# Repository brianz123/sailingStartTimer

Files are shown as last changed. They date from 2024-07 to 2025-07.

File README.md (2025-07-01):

# Sailing Start Timer

This project is a microcontroller-based horn system designed to automate race starts for sailboat regattas. It replaces manual countdowns and whistle systems with a reliable, consistent, and rugged solution tailored to race officials on the water.

## Summary

The Sailing Start Timer outputs a sequence of horn blasts that follow standard sailing race countdown rules. A single button press initiates the sequence, allowing race officials to focus on managing boats instead of watching the clock. The system is built with an Arduino and a waterproof speaker, and was designed to be both portable and weather-resistant.

## Features

- Automated horn sequence for 5-minute, 3-minute, or custom countdowns
- One-button operation for simple race start triggering
- Loud, waterproof horn for outdoor use
- Rugged and portable design suitable for mark boats or committee boats
- Custom enclosure and PCB designed for durability

## Hardware

- Arduino microcontroller
- Waterproof speaker module
- Push-button input
- Custom 3D-printed or machined enclosure
- Power system for extended outdoor operation (e.g. 12V or battery pack)

## Software

- Written in Arduino C++
- Timer-based logic to produce horn blasts at key intervals
- Debounced user input handling
- Configurable countdown intervals via code or DIP switches (if implemented)

## How It Works

1. User presses a button to trigger the countdown.
2. The microcontroller runs a timed sequence of horn blasts:
   - Long horn at 5:00
   - Warning signals at 4:00, 1:00, and 0:00 (based on racing rules)
3. Horn blasts are output through a waterproof horn module at full volume.
4. System resets automatically or after user input.

## Use Case

This device is intended for use by sailing race officials on the water. It simplifies race starts, ensures consistent timing, and reduces errors from manual systems.

## Author

**Brian Zagalsky**

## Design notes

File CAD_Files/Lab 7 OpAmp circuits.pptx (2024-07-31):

## Op Amp: Nearly ideal differential voltage amplifier

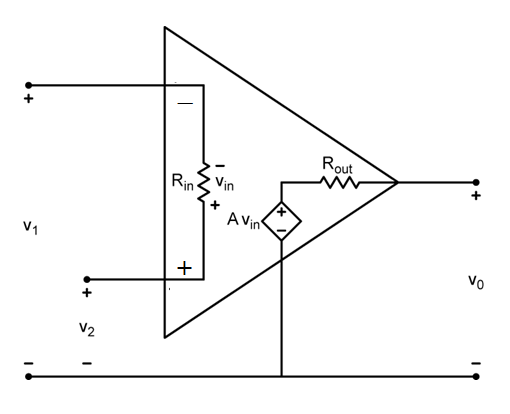
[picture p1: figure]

Ideal op-amp:

A→ ∞

Rin→ ∞

Rout→0

## Before you build a circuit, you need to draw circuit diagram, and a wiring diagram

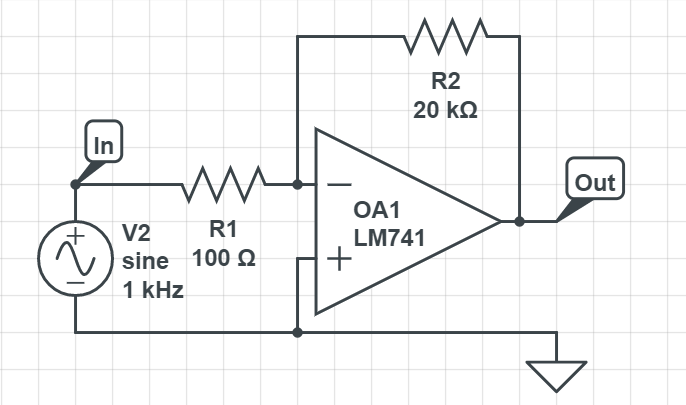
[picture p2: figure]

This is a circuit diagram:

Wiring diagram includes the connections specific pins on the chip,
and to the power supplies

## This is a wiring diagram for non-inverting amplifier

V ⁻

V⁺

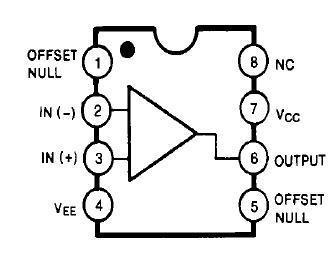
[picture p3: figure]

Input signal

Output
to oscilloscope

R1

R2

Ground

Ground

## Inverting amplifier

vs

+

R1

v1

v2

+

+
Vout

R2

This amplifier works as designed provided Vout is in the range
between V⁻ and V⁺

Clipping of output signal occurs when the amplitude of Vout is too high

## Summing amplifier

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
vout

Vout= - Rf (VS1/R1+VS2/R2)

## Different pulse shapes can be observed when we add harmonics to sinusoidal signals

clear
t=0:1000;
omega=2*pi/200;
V1=cos(omega*t)-(1/3)*cos(3*omega*t)
+(1/5)*cos(5*omega*t);
figure(1);plot(t,V1)

With large number of harmonics
the output approaches the
square wave

## Different pulse shapes can be observed when we add harmonics to sinusoidal signals

clear
t=0:1000;
omega=2*pi/200;
V1=cos(omega*t)+(1/3)*cos(3*omega*t)
+(1/5)*cos(5*omega*t);
figure(1);plot(t,V1)

With large number of harmonics
the output approaches the
triangular wave

## All real amplifiers have a finite bandwidths

Bandwidth is the range of frequencies
for which the device works properly

Our OpAmp circuits work well for low frequencies, down to DC

Bandwidth in this case is defined as the frequency
for which the output power gain is down to 50%
of the design value

Important trade off:
Gain * Bandwidth is approximately a constant

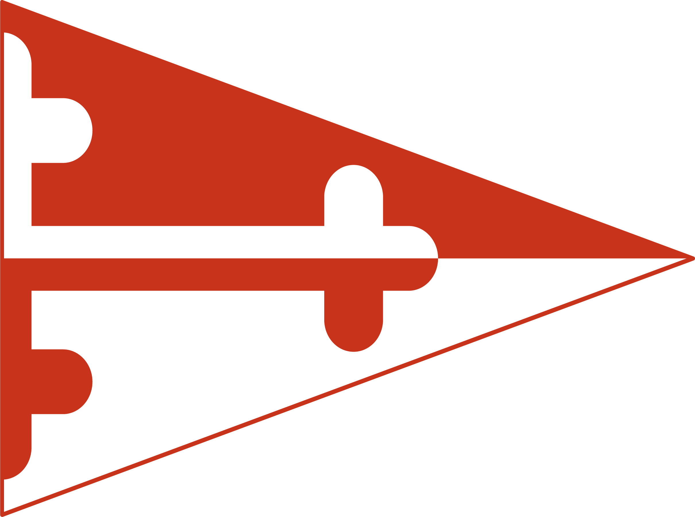
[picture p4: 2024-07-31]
CAD_Files/Burgee.png

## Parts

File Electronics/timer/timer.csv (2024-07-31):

Source: | C:\Users\Brian\Documents\ESP\timer\timer.kicad_sch
Date: | 1/15/2023 2:08:23 PM
Tool: | Eeschema (6.0.7)
Generator: | C:\Program Files\KiCad\6.0\bin\scripting\plugins/bom_csv_grouped_by_value_with_fp.py
Component Count: | 14
Ref | Qnty | Value | Cmp name | Footprint | Description | Vendor
BT1, | 1 | Battery | Battery | Connector_PinSocket_1.00mm:PinSocket_1x02_P1.00mm_Vertical | Multiple-cell battery
LS1, | 1 | Speaker | Speaker | Connector_PinHeader_2.54mm:PinHeader_1x02_P2.54mm_Vertical | Speaker
Q1, | 1 | IRFZ48 | IRFZ48 | Connector_PinHeader_1.00mm:PinHeader_1x03_P1.00mm_Vertical
R1, R2, R3, R4, R5, | 5 | 10k | R | Resistor_THT:R_Axial_DIN0204_L3.6mm_D1.6mm_P7.62mm_Horizontal | Resistor
R6, | 1 | 2.2k | R | Resistor_THT:R_Axial_DIN0204_L3.6mm_D1.6mm_P7.62mm_Horizontal | Resistor
SW1, | 1 | Reset | SW_Push | Button_Switch_THT:SW_PUSH_6mm_H4.3mm | Push button switch, generic, two pins
SW2, | 1 | 2 Min | SW_Push | Button_Switch_THT:SW_PUSH_6mm_H4.3mm | Push button switch, generic, two pins
SW3, | 1 | 3 Min | SW_Push | Button_Switch_THT:SW_PUSH_6mm_H4.3mm | Push button switch, generic, two pins
SW4, | 1 | 5 Min | SW_Push | Button_Switch_THT:SW_PUSH_6mm_H4.3mm | Push button switch, generic, two pins
v1, | 1 | Node_MCU | Node_MCU | ESP:Node MCU

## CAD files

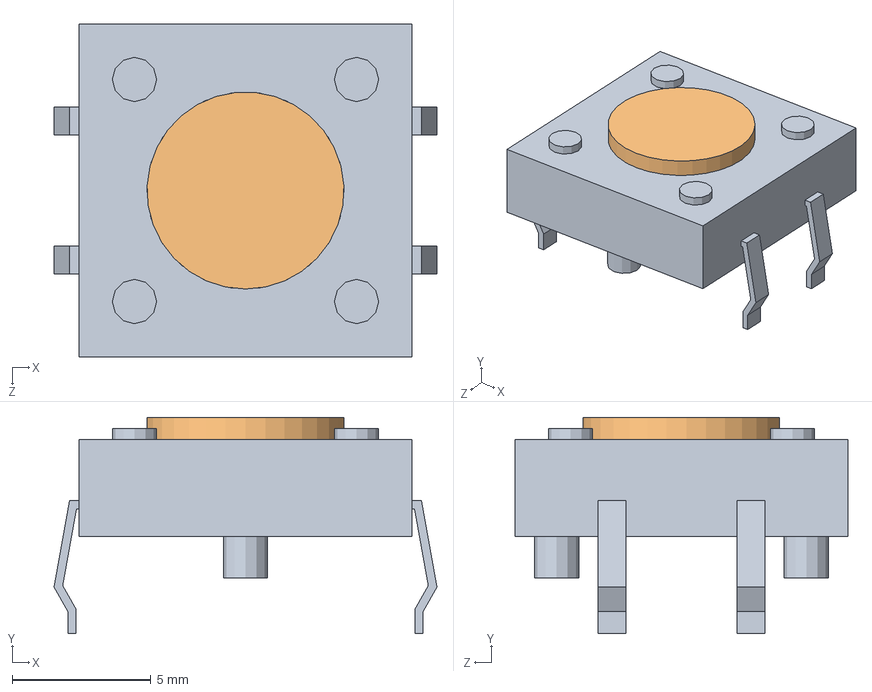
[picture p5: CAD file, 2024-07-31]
CAD_Files/B3F_4000_Solidworks/B3F_4000.SLDASM
13.8 x 7.80 x 12.0 mm
B3F_4000_BASE
B3F_4000_BUTTON

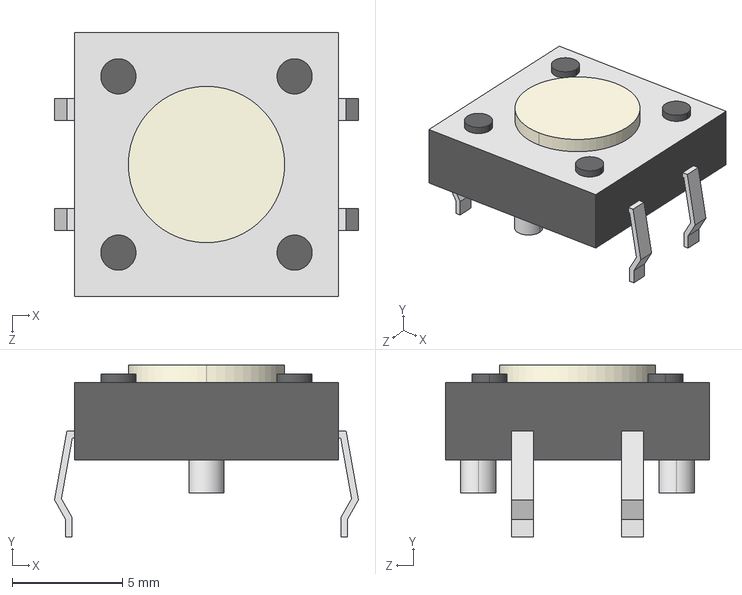
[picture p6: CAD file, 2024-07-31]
CAD_Files/B3F_4000_Solidworks/SW_PUSH_12mm.STEP
13.8 x 7.80 x 12.0 mm
B3F_4000_BASE
B3F_4000_BUTTON

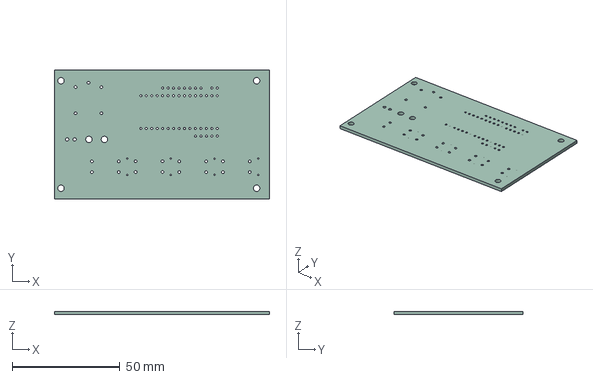
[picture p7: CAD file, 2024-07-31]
CAD_Files/timer.step
100.0 x 60.0 x 1.60 mm

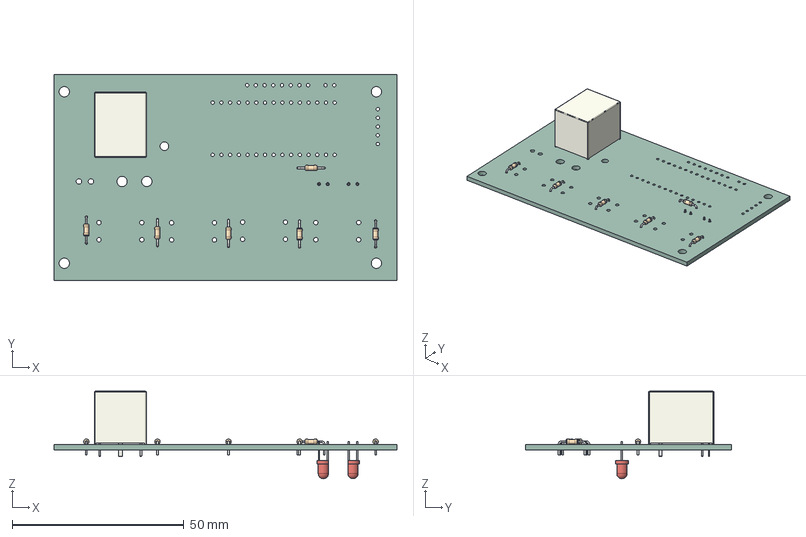
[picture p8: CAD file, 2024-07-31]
Electronics/Timer V4/Timer V4.step
100.0 x 60.0 x 25.5 mm
Timer V4 PCB

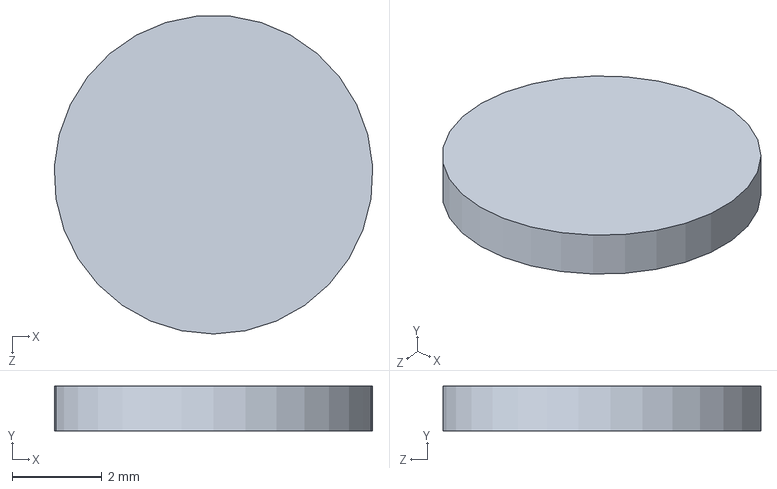
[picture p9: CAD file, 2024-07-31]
CAD_Files/B3F_4000_Solidworks/B3F_4000_BUTTON.SLDPRT
7.09 x 1.00 x 7.08 mm

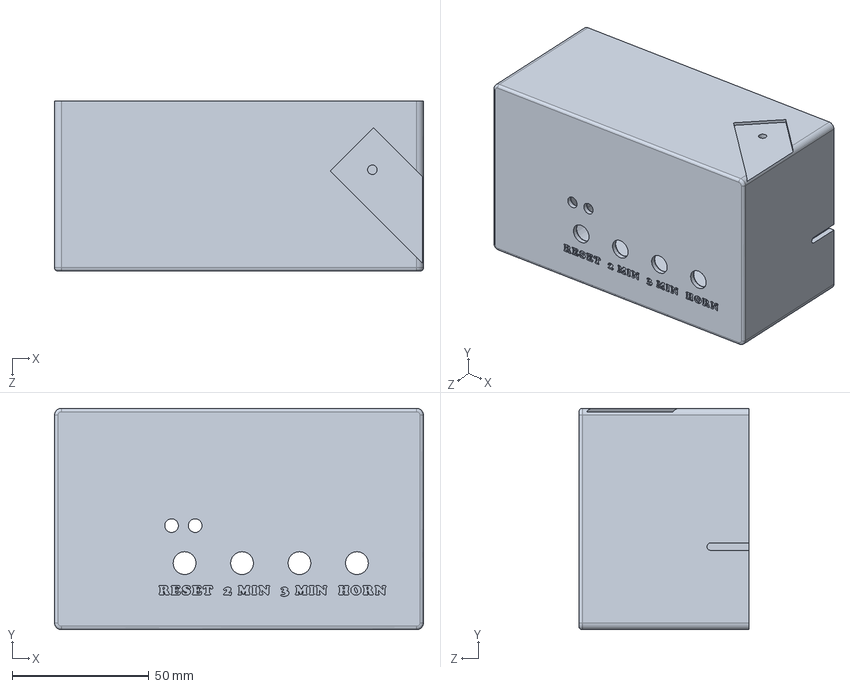
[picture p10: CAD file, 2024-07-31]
CAD_Files/timerBox.SLDPRT
135.0 x 81.0 x 62.2 mm

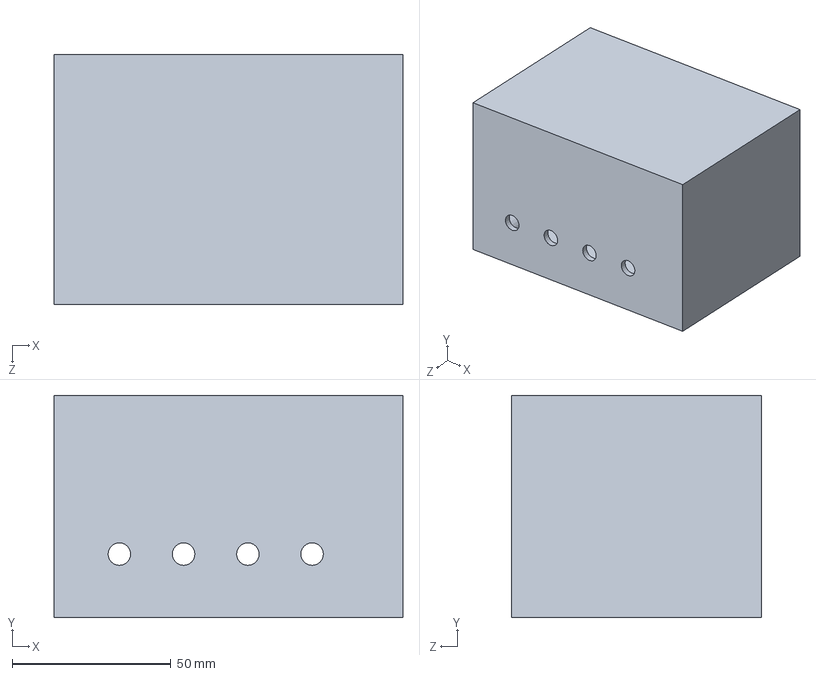
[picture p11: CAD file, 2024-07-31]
CAD_Files/Part1.SLDPRT
110.0 x 70.0 x 78.7 mm

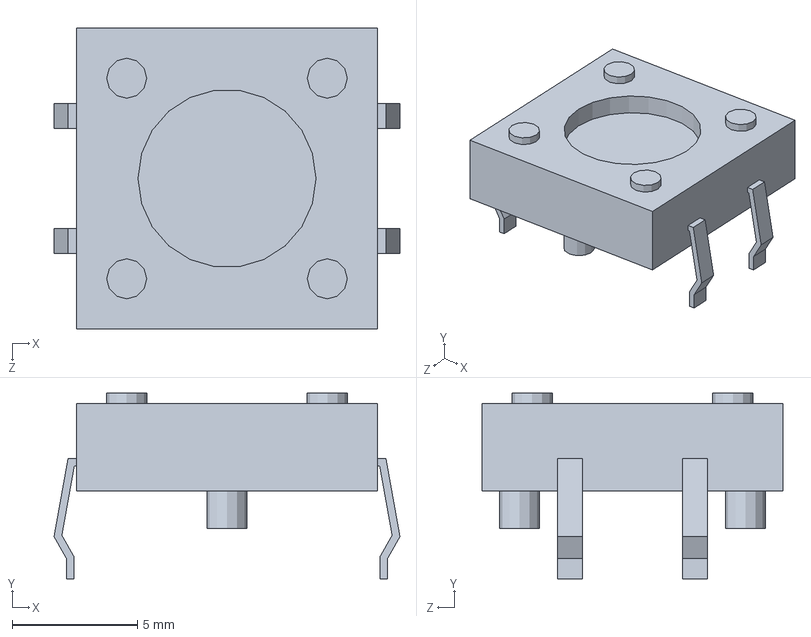
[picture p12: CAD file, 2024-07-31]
CAD_Files/B3F_4000_Solidworks/B3F_4000_BASE.SLDPRT
13.8 x 7.40 x 12.0 mm

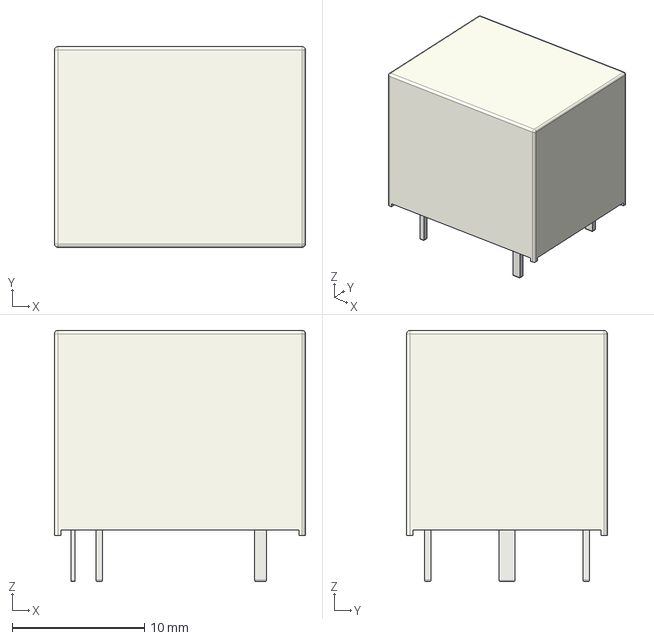
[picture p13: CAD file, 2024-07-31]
CAD_Files/Relay_SPDT_Finder_36.11.step
19.0 x 15.2 x 19.0 mm

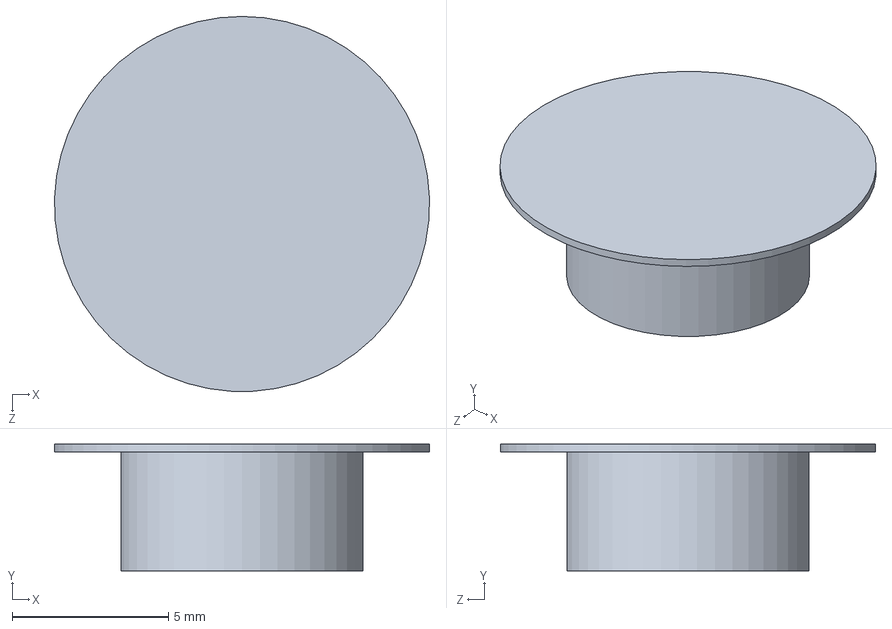
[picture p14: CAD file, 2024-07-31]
CAD_Files/buttunCap.SLDPRT
12.0 x 4.06 x 12.0 mm

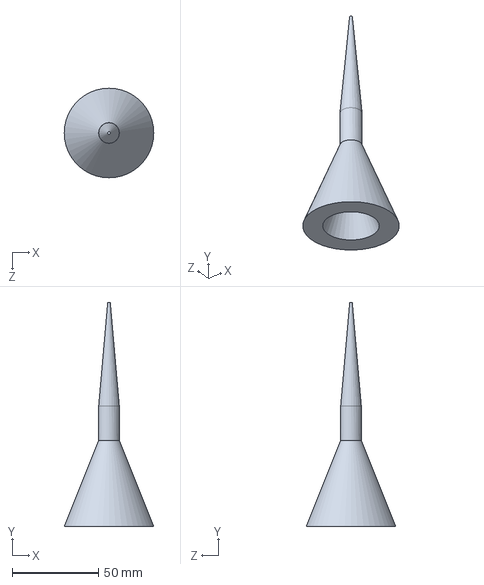
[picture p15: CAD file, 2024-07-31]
CAD_Files/funnel.SLDPRT
52.0 x 130.0 x 52.0 mm

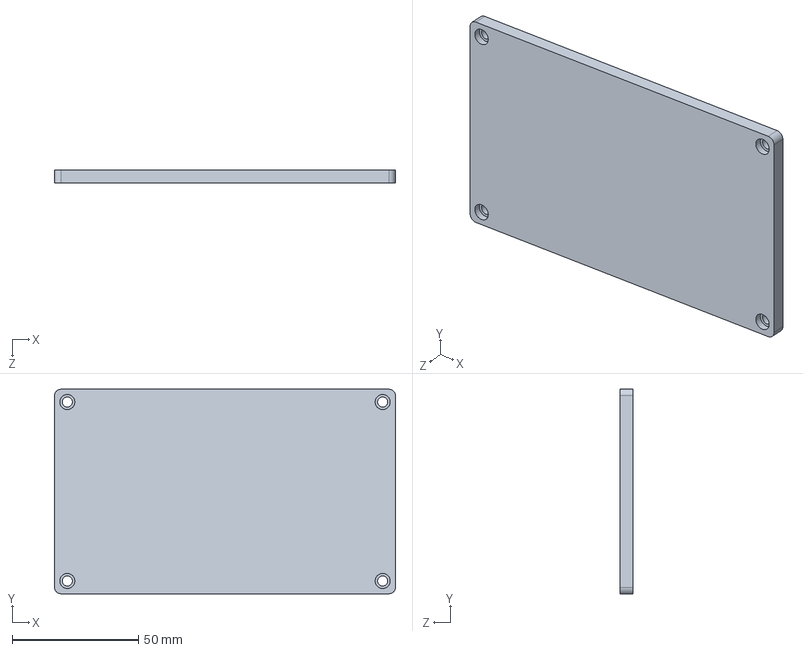
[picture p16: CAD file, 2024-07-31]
CAD_Files/door.SLDPRT
135.0 x 81.0 x 5.08 mm

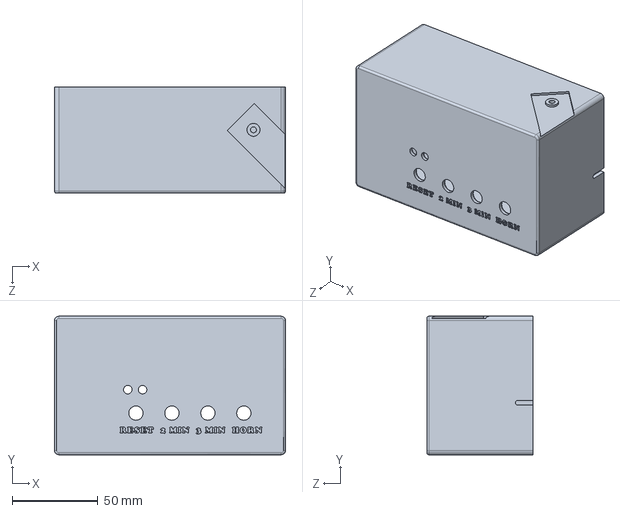
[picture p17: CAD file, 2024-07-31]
CAD_Files/timerBoxV2.SLDPRT
135.0 x 81.0 x 62.2 mm

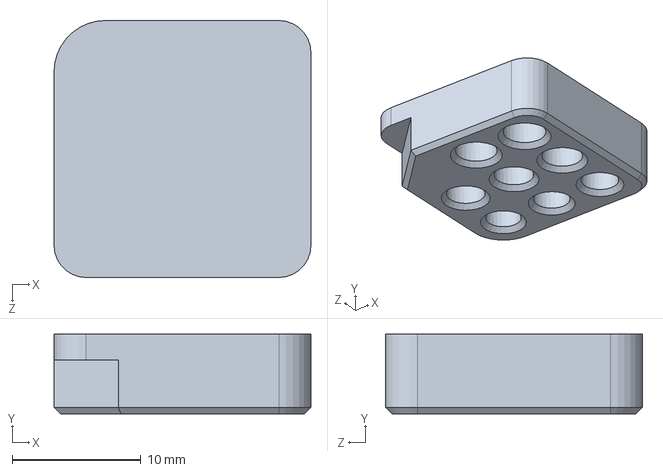
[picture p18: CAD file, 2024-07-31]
CAD_Files/nutTester.SLDPRT
20.0 x 6.20 x 20.0 mm

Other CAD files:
CAD_Files/door V4.STL
CAD_Files/R_Axial_DIN0207_L6.3mm_D2.5mm_P7.62mm_Horizontal.step
CAD_Files/dorr.SLDPRT
CAD_Files/funnelSMALL.STL
CAD_Files/B3F_4000_Solidworks/B3F_4000.SLDDRW
CAD_Files/buttunCap.STL
CAD_Files/door.STL
CAD_Files/funnel.STL
CAD_Files/nutTester.STL
CAD_Files/timer.SLDASM
CAD_Files/timer.STL
CAD_Files/timerBox V4.STL
CAD_Files/timerBox.STL
CAD_Files/timerBoxV2.STL

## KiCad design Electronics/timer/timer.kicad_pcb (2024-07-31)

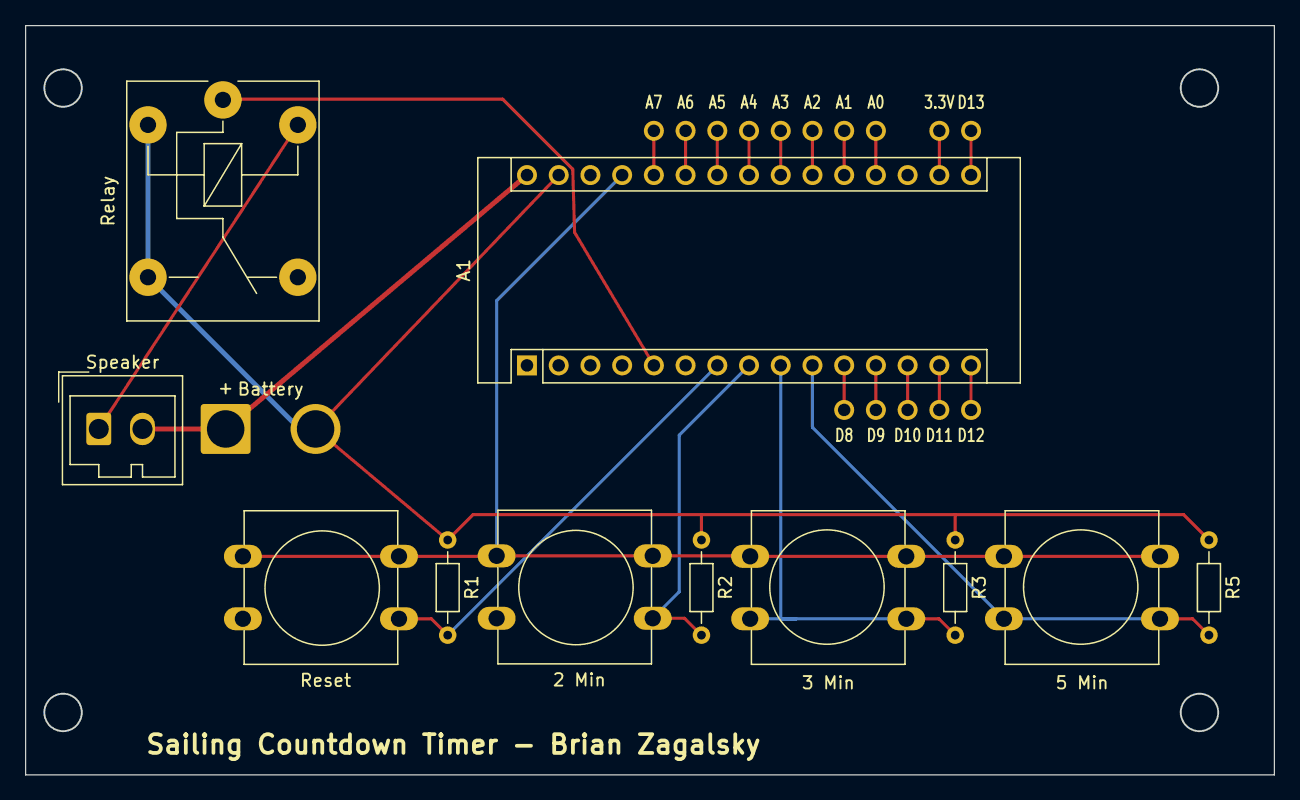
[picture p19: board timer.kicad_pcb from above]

Board: 2 copper layers, 100.0 x 60.0 mm, 27 parts (0 on the bottom side), 9 nets.

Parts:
3.3V: MountingHole_1.2mm
A0, A1, A2, A3, A4, A5, A6, A7: MountingHole_1.2mm
A1#2: Arduino_Nano_v3.x; Arduino_Nano
Battery: Battery; SolderWire-2.5sqmm_1x02_P7.2mm_D2.4mm_OD3.6mm
D8, D9, D10, D11, D12, D13: MountingHole_1.2mm
R1, R2, R3, R5: 10k; R_Axial_DIN0204_L3.6mm_D1.6mm_P7.62mm_Horizontal
Relay: FINDER-36.11; Relay_SPDT_Finder_36.11
SW1: Reset; SW_PUSH-12mm
SW2: 2 Min; SW_PUSH-12mm
SW3: 3 Min; SW_PUSH-12mm
SW4: 5 Min; SW_PUSH-12mm
Speaker: Speaker; Wago_734-132_1x02_P3.50mm_Vertical

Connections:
unnamed: A1#2.5 (D2), Relay.11
unnamed: Relay.A2, Speaker.1
unnamed: A1#2.30 (VIN), Battery.1 (+), Speaker.2
unnamed: A1#2.7 (D4), R1.2, SW1.2
unnamed: A1#2.8 (D5), R2.2, SW2.2
unnamed: A1#2.9 (D6), R3.2, SW3.1
unnamed: A1#2.10 (D7), R5.2, SW4.1
unnamed: A1#2.27 (+5V), SW1.1, SW2.1, SW3.2, SW4.2
unnamed: A1#2.29 (GND), Battery.2 (-), R1.1, R2.1, R3.1, R5.1, Relay.14, Relay.A1

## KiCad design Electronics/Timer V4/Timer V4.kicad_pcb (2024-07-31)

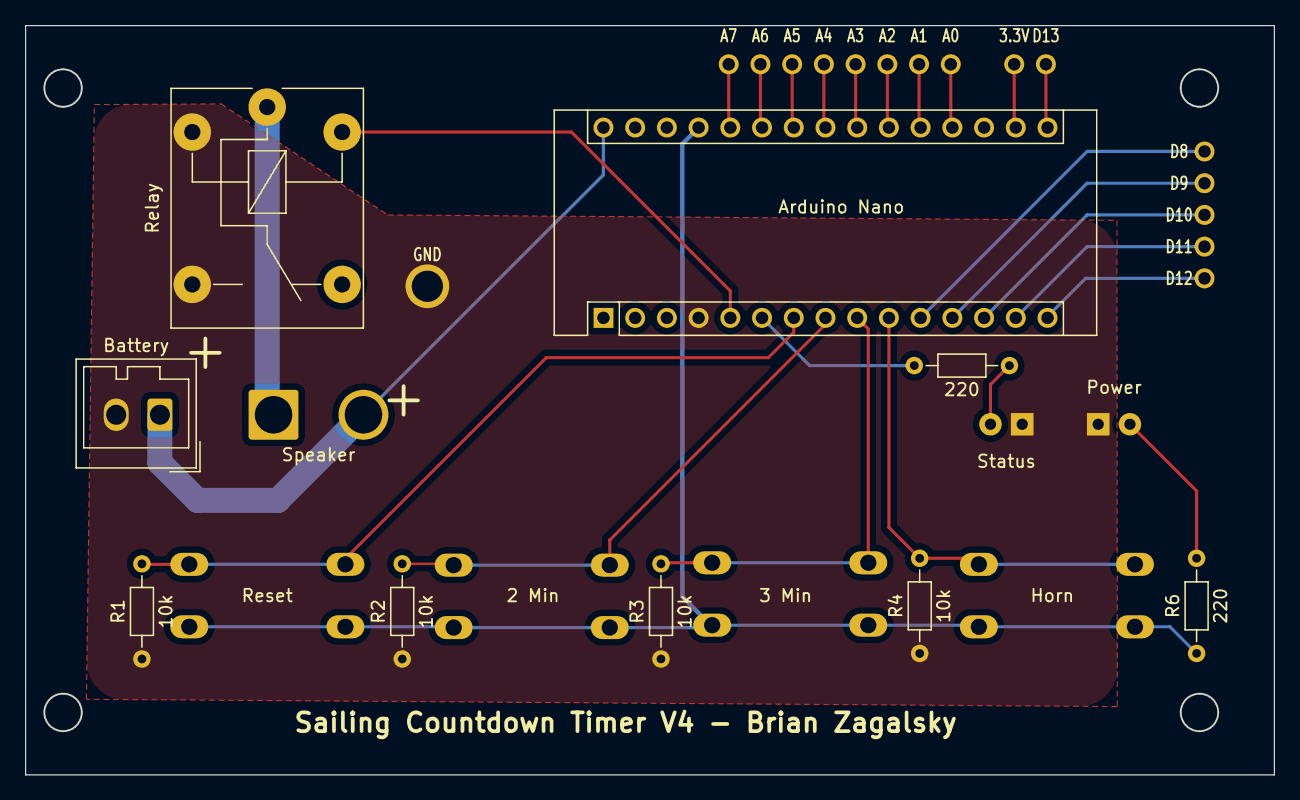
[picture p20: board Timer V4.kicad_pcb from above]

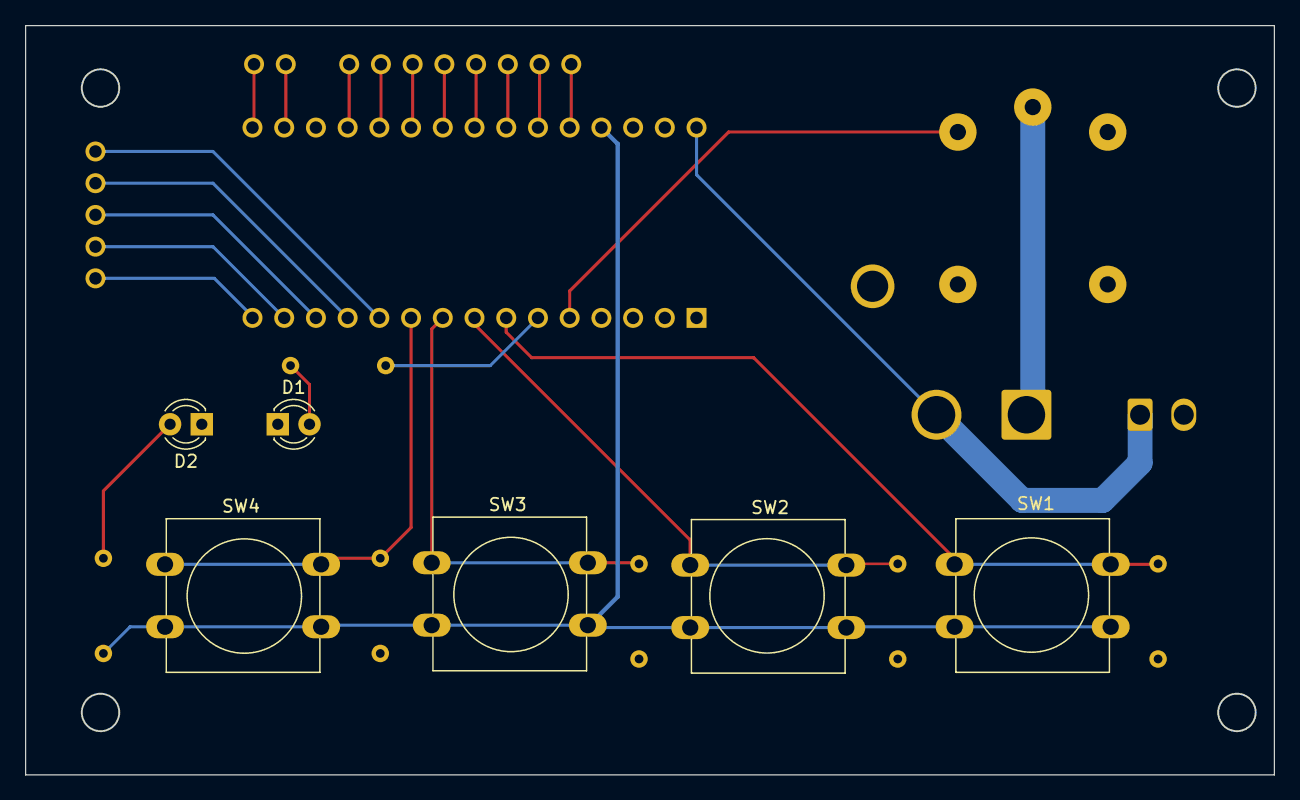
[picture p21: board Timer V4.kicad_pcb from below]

Board: 2 copper layers, 100.0 x 60.0 mm, 32 parts (6 on the bottom side), 12 nets.

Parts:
3.3V: MountingHole_1.2mm
A0, A1, A2, A3, A4, A5, A6, A7: MountingHole_1.2mm
A1#2: Arduino Nano; Arduino_Nano
D1: Status; LED_D3.0mm
D2: Power; LED_D3.0mm
D8, D9, D10, D11, D12, D13: MountingHole_1.2mm
GND: MountingHole_1.2mm
LS1: Speaker; SolderWire-2.5sqmm_1x02_P7.2mm_D2.4mm_OD3.6mm
R1, R2, R3, R4: 10k; R_Axial_DIN0204_L3.6mm_D1.6mm_P7.62mm_Horizontal
R5, R6: 220; R_Axial_DIN0204_L3.6mm_D1.6mm_P7.62mm_Horizontal
Relay: FINDER-36.11; Relay_SPDT_Finder_36.11
SW1: Reset; SW_PUSH-12mm
SW2: 2 Min; SW_PUSH-12mm
SW3: 3 Min; SW_PUSH-12mm
SW4: Horn; SW_PUSH-12mm
V1: Battery; Wago_734-132_1x02_P3.50mm_Vertical

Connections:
/GND: A1#2.4 (GND), D1.1 (K), D2.1 (K), R1.1, R2.1, R3.1, R4.1, Relay.14, Relay.A1, V1.2 (-)
unnamed: A1#2.5 (D2), Relay.A2
unnamed: A1#2.6 (D3), R5.1
unnamed: A1#2.7 (D4), R1.2, SW1.2
unnamed: A1#2.8 (D5), R2.2, SW2.2
unnamed: A1#2.9 (D6), R3.2, SW3.1
unnamed: A1#2.10 (D7), R4.2, SW4.1
unnamed: A1#2.27 (+5V), R6.1, SW1.1, SW2.1, SW3.2, SW4.2
unnamed: A1#2.30 (VIN), LS1.2, V1.1 (+)
unnamed: D1.2 (A), R5.2
unnamed: D2.2 (A), R6.2
unnamed: LS1.1, Relay.11

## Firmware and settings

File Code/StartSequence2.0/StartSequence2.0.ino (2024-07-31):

// define button pins
#define RESET_BUTTON_PIN 4
#define MIN2_BUTTON_PIN 5
#define MIN3_BUTTON_PIN 6
#define MIN5_BUTTON_PIN 7
#define LED 3
#define RELAY_PIN 2
#define waitTime 500
// define variables to track timer state
int sec = 0;
unsigned long startTime = 0;
bool min2_state = false;
bool min3_state = false;
bool min5_state = false;
bool rst_state = false;
int timerlen = 0;

//void handleInterrupt() {
//  if (digitalRead(MIN5_BUTTON_PIN) == LOW) {
//    digitalWrite(RELAY_PIN, LOW);
//  } else {
//    digitalWrite(RELAY_PIN, HIGH);
//  }
//}

void setup() {
  // initialize serial communication
  Serial.begin(115200);
  pinMode(LED, OUTPUT);
  pinMode(RESET_BUTTON_PIN, INPUT);
  pinMode(MIN2_BUTTON_PIN, INPUT);
  pinMode(MIN3_BUTTON_PIN, INPUT);
  pinMode(MIN5_BUTTON_PIN, INPUT);  // Enable internal pull-up resistor
  pinMode(RELAY_PIN, OUTPUT);

  // Set interrupt on change for MIN5_BUTTON_PIN
  //  attachInterrupt(digitalPinToInterrupt(MIN5_BUTTON_PIN), handleInterrupt, CHANGE);

  Serial.println("Starting");
  digitalWrite(RELAY_PIN, 0);
  digitalWrite(LED, HIGH);
  delay(500);
  digitalWrite(LED, LOW);
}


void loop() {
  digitalWrite(LED, LOW);
  updatebuttons();
  updateTimer(startTime);
  if (min2_state) timerlen = 2;
  else if (min3_state) timerlen = 3;
  else if (min5_state) timerlen = 5;
  else {
    Serial.print("no time selcted");
    digitalWrite(RELAY_PIN, 0);
    timerlen = 0;
    startTime = 0;
    sec = 0;
  }
  min2_state = 0;
  min3_state = 0;
  min5_state = 0;
  switch (timerlen) {
    case 5:
    digitalWrite(LED, HIGH);
      digitalWrite(RELAY_PIN, HIGH);
      delay(2);
      Serial.println("horn");
//      delay(150);
      break;
    case 3:
     digitalWrite(LED, HIGH);
      digitalWrite(RELAY_PIN, 0);
      threeMin();
      Serial.println("3 minute Timer startTime");
      break;
    case 2:
     digitalWrite(LED, HIGH);
      digitalWrite(RELAY_PIN, 0);
      twoMin();
      Serial.println("2 minute Timer startTime");
      break;
  }
  timerlen = 0;
}
void fiveMin() {
  startTime = millis();
  delay(200);
  sec = (millis() - startTime) / 1000;
  //5 min = 300s; 4 min = 240s; 3 min = 180s; 2 min = 120s; 1.5 min = 90s; 1 min = 60s
  while (sec < 300) {
    if (!updateTimer(startTime)) return;
    //    sec = (millis() - startTime) / 1000;
    delay(50);
    switch (300 - sec) {
      case 300:
        longBlast(5);
        break;
      case 180:
        longBlast(3);
        break;
      case 120:
        longBlast(2);
        break;
      case 90:
        longBlast(1);
        shortBlast(3);
        break;
      case 60:
        longBlast(1);
        break;
      case 30:
        shortBlast(3);
        break;
      case 20:
        shortBlast(2);
        break;
      case 10:
        shortBlast(1);
        break;
      case 0:
        go(startTime);
        break;
    }
    sec = (millis() - startTime) / 1000;
  }
}

void threeMin() {
  startTime = millis();
  delay(200);
  sec = (millis() - startTime) / 1000;
  //  3 min = 180s; 2 min = 120s; 1.5 min = 90s; 1 min = 60s
  while (sec < 180) {
    if (!updateTimer(startTime)) return;
    //    sec = (millis() - startTime) / 1000;
    delay(50);
    switch (180 - sec) {
      case 180:
        longBlast(3);
        break;
      case 120:
        longBlast(2);
        break;
      case 90:
        longBlast(1);
        shortBlast(3);
        break;
      case 60:
        longBlast(1);
        break;
      case 30:
        shortBlast(3);
        break;
      case 20:
        shortBlast(2);
        break;
      case 10:
        shortBlast(1);
        break;
      case 5:
        go(startTime);
        break;
    }
    sec = (millis() - startTime) / 1000;
    if (!updateTimer(startTime)) return;
  }
}

void twoMin() {
  Serial.println("two minutes");
  startTime = millis();
  if (!updateTimer(startTime)) return;
  delay(200);
  sec = (millis() - startTime) / 1000;
  //2 min = 120s; 1.5 min = 90s; 1 min = 60s
  while (sec < 120) {

    //    sec = (millis() - startTime) / 1000;
    delay(50);
    switch (120 - sec) {
      case 120:
        {
          longBlast(2);
        }
        break;
      case 90:
        {
          longBlast(1);
          shortBlast(3);
        }
        break;
      case 60:
        {
          longBlast(1);
        }
        break;
        break;
      case 30:
        {
          shortBlast(3);
        }
        break;
      case 20:
        {
          shortBlast(2);
        }
        break;
      case 10:
        {
          shortBlast(1);
        }
        break;
      case 5:
        {
          go(startTime);
        }
        break;
    }
    //    sec = (millis() - startTime) / 1000;
    if (!updateTimer(startTime)) return;
  }
  updateTimer(startTime);
}

void longBlast(int count) {
  Serial.println("Long Blast start");
  Serial.println(count);
  for (int i = 0; i < count; i++) {
    digitalWrite(RELAY_PIN, HIGH);
    delay(waitTime * 1.25);
    digitalWrite(RELAY_PIN, 0);
    delay(200);
    if (!updateTimer(startTime)) return;
  }
  delay(250);
  Serial.println("Long Blast end");
}

void shortBlast(int count) {
  for (int i = 0; i < count; i++) {
    digitalWrite(RELAY_PIN, HIGH);
    delay(waitTime / 3);
    digitalWrite(RELAY_PIN, 0);
    delay(200);
    if (!updateTimer(startTime)) return;
  }
}

void go(int startTime) {
  for (int i = 0; i < 5; i++) {
    digitalWrite(RELAY_PIN, HIGH);
    delay(750);
    digitalWrite(RELAY_PIN, 0);
    delay(250);
    if (!updateTimer(startTime)) return;
  }
  digitalWrite(RELAY_PIN, HIGH);
  delay(3000);
  digitalWrite(RELAY_PIN, 0);
}

void updatebuttons() {
  rst_state = 0;
  min2_state = 0;
  min3_state = 0;
  min5_state = 0;
  for (int i = 0; i < 25; i++) {
    if (rst_state == LOW) {
      rst_state = digitalRead(RESET_BUTTON_PIN);
    }
    if (min2_state == LOW)
      min2_state = digitalRead(MIN2_BUTTON_PIN);
    if (min3_state == LOW)
      min3_state = digitalRead(MIN3_BUTTON_PIN);
    if (min5_state == LOW)
      min5_state = digitalRead(MIN5_BUTTON_PIN);
    delay(1);
  }
}

bool updateTimer(int startTime) {
  if (digitalRead(RESET_BUTTON_PIN) == HIGH) {
    Serial.println("reset");
    return false;
  }
  sec = (millis() - startTime) / 1000;
  String out = String((timerlen * 60 - sec) / 60);
  out += ":";
  out += String((timerlen * 60 - sec - ((timerlen * 60 - sec) / 60) * 60) % 60);
  if (startTime == 0) out = "0:00";
  // else
  // Serial.println(out);
  delay(2);
  return true;
}

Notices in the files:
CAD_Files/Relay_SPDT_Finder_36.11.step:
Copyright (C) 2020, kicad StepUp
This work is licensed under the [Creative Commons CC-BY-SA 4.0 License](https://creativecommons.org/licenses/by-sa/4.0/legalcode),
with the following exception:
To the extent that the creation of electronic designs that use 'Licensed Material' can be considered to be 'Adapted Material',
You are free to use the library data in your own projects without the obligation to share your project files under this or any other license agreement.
